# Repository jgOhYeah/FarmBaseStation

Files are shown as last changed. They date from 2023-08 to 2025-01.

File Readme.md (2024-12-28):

# Base station for connecting remote sensors to Thingsboard.
Remote sensors use [PJON over LoRa](https://github.com/gioblu/PJON) radio to communicate.
The [Thingsboard Gateway MQTT API](https://thingsboard.io/docs/reference/gateway-mqtt-api/) is used to connect on the Thingsboard side.

See [here](https://github.com/jgOhYeah/Farm-PJON-LoRa-network) for other sensors and more information on the system.

Written by Jotham Gates
August 2023

## Photos
<!-- <img src="Photos/Inside.jpg" alt="Inside the enclosure." width="50%">
<img src="Photos/Completed.jpg" alt="The completed unit." width="49%"> -->
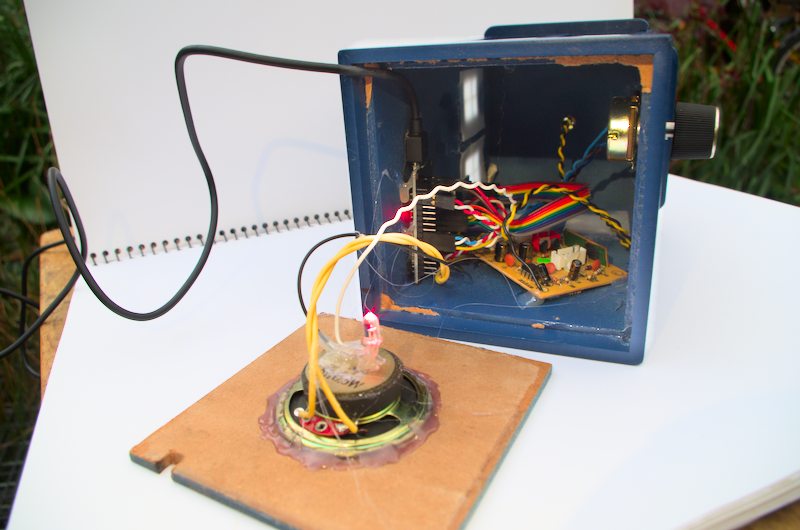
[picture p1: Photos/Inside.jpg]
Inside the enclosure.

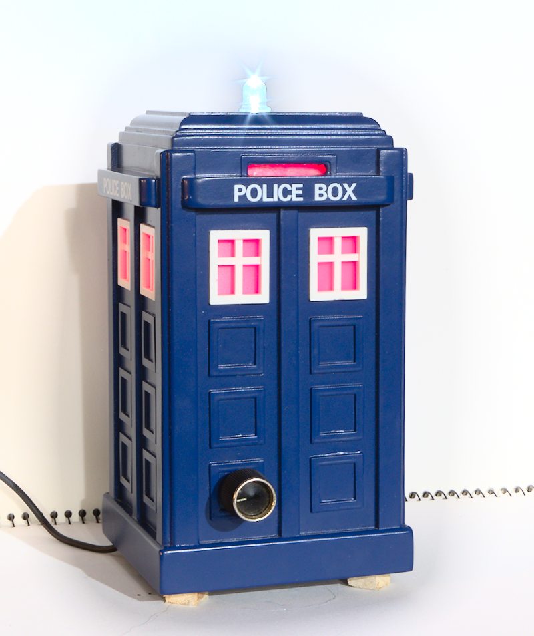
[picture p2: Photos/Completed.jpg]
The completed unit.


## Getting started
The Github repository containing all design files and code is [here](https://github.com/jgOhYeah/FarmBaseStation).

1. Install Platform IO.
2. Open the project in the [`BaseStationCode`](./BaseStationCode/) directory.
3. Create a copy of [`BaseStationCode/credentials.example.ini`](./BaseStationCode/credentials.example.ini) and name this `credentials.ini`. Fill out the settings in this file for the WiFi network to connect to, MQTT broker, Thingsboard credentials and Over The Air (OTA) update settings.
4. Upload the code to the ESP32.
5. Assemble the electronics as shown in the schematics and optionally place inside a case.
6. Test with other sensors and the Thingsboard server.

## Updating using OTA updates
Over the air (OTA) updates can be used to update the software on the base station once it has been programmed for the first time. To do this:
1. Edit the upload port and auth flags in `credentials.ini` to match those currently set on the device.
2. Change the active Platform IO environment to `Tardis-OTA` from its default `Tardis` environment (likewise for the `TVAnt` environemnt for ethernet).
3. Compile and upload code as normal.

## Schematics
The base station uses an ESP32 development board as its base. An SX1278 LoRa radio module breakout board is connected via jumper leads. LEDs are soldered along with their respective current limiting resistors to wires that can be plugged into the ESP32 board. An audio amplifier and speaker can also be connected for alarm functionality. I salvaged this from the sound effects module of a broken children's ride on toy car.

The schematic for the base station

## Fun part / experiments
I originally planned to use the build in DAC of the ESP32 to play sounds on alarm conditions. At this point I haven't succeded in this (currently using the [TunePlayer](https://github.com/jgOhYeah/TunePlayer) library to play simple monotonic songs instead). I did come across the [ESP32-A2DP](https://github.com/pschatzmann/ESP32-A2DP) library that allows the use of this unit as a terrible sounding bluetooth speaker.

[This sketch](Fun/BluetoothSpeaker/BluetoothSpeaker.ino) is the `bt_music_receiver_to_internal_dac` example from the ESP32-A2DP library with the addition of flashing lights.

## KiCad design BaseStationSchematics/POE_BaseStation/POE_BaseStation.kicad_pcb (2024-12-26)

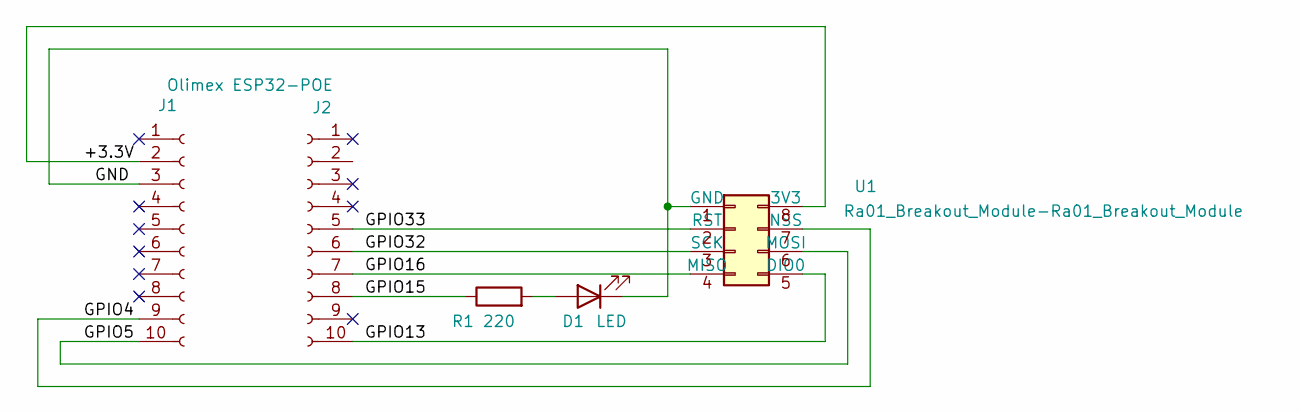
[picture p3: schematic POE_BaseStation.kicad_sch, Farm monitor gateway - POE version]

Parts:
D1: LED; LED_D3.0mm
J1: Olimex ESP32-POE; PinSocket_1x10_P2.54mm_Vertical
J2: Conn_01x10_Socket; PinSocket_1x10_P2.54mm_Vertical
R1: 220; R_Axial_DIN0207_L6.3mm_D2.5mm_P15.24mm_Horizontal
U1: Ra01_Breakout_Module-Ra01_Breakout_Module; DIP-8_W7.62mm_Socket_LongPads

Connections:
/+3.3V: J1.2, U1.8 (3V3)
/GND: D1.1 (K), J1.3, U1.1 (GND)
/GPIO4: J1.9, U1.7 (NSS)
/GPIO5: J1.10, U1.6 (MOSI)
/GPIO13: J2.10, U1.5 (DIO0)
/GPIO15: J2.8, R1.1
/GPIO16: J2.7, U1.4 (MISO)
/GPIO32: J2.6, U1.3 (SCK)
/GPIO33: J2.5, U1.2 (RST)
unnamed: D1.2 (A), R1.2

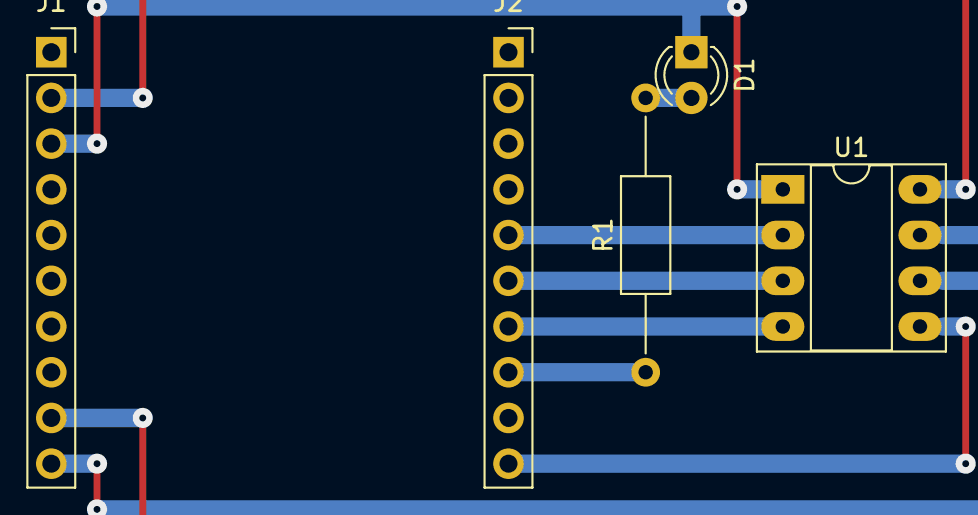
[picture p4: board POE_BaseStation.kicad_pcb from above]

Board: 2 copper layers, 5 parts (0 on the bottom side), 10 nets.

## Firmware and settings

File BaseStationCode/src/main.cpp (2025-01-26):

/**
 * @file ESP32BaseStation.ino
 * @brief Main file for a base station to connect to remote sensors on a farm.
 *
 * This is a base station to convert between PJON through LoRa to Thingsboard
 * MQTT.
 *
 * @author Jotham Gates
 * @version 0.1
 * @date 2024-12-19
 */
#include "defines.h"

#ifdef USE_ETHERNET
NetworkClient client;
PubSubClient mqtt(client);
bool ethernetConnected = false;
#else
WiFiClient wifi;
PubSubClient mqtt(wifi);
#endif
PJONThroughLora bus(PJON_DEVICE_ID);
QueueHandle_t alarmQueue;
#ifdef PIN_SPEAKER
QueueHandle_t audioQueue;
#endif
QueueHandle_t mqttPublishQueue;
SemaphoreHandle_t loraMutex;
SemaphoreHandle_t mqttMutex;
SemaphoreHandle_t serialMutex;

#include "device_list.h"
#include "src/networking.h"
#include "src/lora.h"
#include "src/rpc.h"
#include "src/alarm.h"
#include "src/audio.h"
#include "src/leds.h"
#include "src/ota.h"
#include "src/timeseries.h"

// States used for LED control.
SemaphoreHandle_t stateUpdateMutex;
AlarmState alarmState;
NetworkState networkState;
uint32_t lastLoRaTime;
TaskHandle_t ledTaskHandle;
bool otaUpdating = false;

#ifdef PIN_IR
#include "hvacir.h"
HVAC airConditioner(PIN_IR);
#endif

#define PIO_VERSION_STR "Env=" PIO_ENV ", Platform=" PIO_PLATFORM " (" PIO_PLATFORM_VERSION "), FRAMEWORK=" PIO_FRAMEWORK "."

void setup()
{
#ifdef PIN_SPEAKER
    // In case a reset pccured at the wrong time.
    pinMode(PIN_SPEAKER, OUTPUT);
    digitalWrite(PIN_SPEAKER, LOW);
    audioQueue = xQueueCreate(3, sizeof(AlarmState));
#endif

    // Setup queues and mutexes
    // TODO: Swap to notifications
    alarmQueue = xQueueCreate(3, sizeof(AlarmState));
    mqttPublishQueue = xQueueCreate(15, sizeof(MqttMsg));
    mqttMutex = xSemaphoreCreateMutex();
    serialMutex = xSemaphoreCreateMutex(); // Needs to be created before logging anything.
    loraMutex = xSemaphoreCreateMutex();
    stateUpdateMutex = xSemaphoreCreateMutex();

    Serial.begin(SERIAL_BAUD); // Already running from the bootloader.
    // Serial.setDebugOutput(true);
    LOGI("Setup", "Farm PJON LoRa base station v" VERSION ". Compiled " __DATE__ ", " __TIME__ ". Connecting using " CONNECTION_METHOD ".");
    LOGI("Setup", PIO_VERSION_STR);

    if (!alarmQueue ||
#ifdef PIN_SPEAKER
        !audioQueue ||
#endif
        !mqttPublishQueue || !mqttMutex || !serialMutex || !loraMutex || !stateUpdateMutex)
    {
        LOGE("SETUP", "Could not create something!!!");
    }

    // Setup IR pin if fitted
#ifdef PIN_IR
    airConditioner.begin();
#endif

    // Create tasks
    xTaskCreatePinnedToCore(
        networkingTask,
        "Networking",
        4096,
        NULL,
        1,
        NULL,
        1);

    // xTaskCreatePinnedToCore(
    //     fakeReceiveTask,
    //     "FakeData",
    //     4096,
    //     NULL,
    //     1,
    //     NULL,
    //     1);

    xTaskCreatePinnedToCore(
        pjonTask,
        "PJON",
        4096,
        NULL,
        1,
        NULL,
        1);

    xTaskCreatePinnedToCore(
        alarmTask,
        "Alarm",
        4096,
        NULL,
        1,
        NULL,
        1);

#ifdef PIN_SPEAKER
    xTaskCreatePinnedToCore(
        audioTask,
        "Audio",
        2048,
        NULL,
        1,
        NULL,
        1);
#endif

    xTaskCreatePinnedToCore(
        loraTxTask,
        "LoRa TX",
        4096,
        NULL,
        1,
        NULL,
        1);

    xTaskCreatePinnedToCore(
        ledTask,
        "LEDs",
        2048,
        NULL,
        1,
        &ledTaskHandle,
        1);

#ifdef GENERATE_TIMESERIES
    xTaskCreatePinnedToCore(
        timeseriesTask,
        "TS",
        4096,
        NULL,
        1,
        NULL,
        1);
#endif
    // TODO: Actually measure ram and high water marks rather than guessing.

#ifdef OTA_ENABLE
    // Setup OTA
    OTAManager::setupOTA();
#else
    // Don't need the loop, so can remove the main Arduino task.
    vTaskDelete(NULL);
#endif
}

void loop()
{
#ifdef OTA_ENABLE
    OTAManager::handleOTA();
    vTaskDelay(1000 / portTICK_PERIOD_MS);
#endif
}

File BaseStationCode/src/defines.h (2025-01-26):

/**
 * @file defines.h
 * @brief Definitions and other preprocessor and global stuff.
 *
 * @author Jotham Gates
 * @version 0.1
 * @date 2024-12-19
 */
#pragma once

#include <Arduino.h>

// Networking physical layer
#ifdef USE_ETHERNET
#include <ETH.h>
#include <Network.h>
#define CONNECTION_METHOD "Ethernet"
#else
#include <WiFi.h>
#define CONNECTION_METHOD "WiFi"
#endif

// Networking application layers
#include <PubSubClient.h>
#include <ArduinoJson.h>

// LoRa
#define PJON_INCLUDE_TL
#define TL_RESPONSE_DELAY 30 // Started out at 50ms, 20ms is too short, >=30ms works. // The PICAXE microcontrollers on the other end are pretty slow.
#include <PJONThroughLora.h>

// OTA (enable or disable in credentials.h)
#ifdef OTA_ENABLE
#include <ArduinoOTA.h>
#endif

// For alarm tunes
#ifdef PIN_SPEAKER
#include <TunePlayer.h>
#endif

#if defined(GENERATE_TIMESERIES) && defined(USE_BMP180)
#include <Adafruit_BMP085.h>
#endif

#define VERSION "0.2.7"

#define SERIAL_BAUD 115200 // Same as the bootloader.

#define MQTT_TOPIC_SEPARATOR '/'

#define RECONNECT_DELAY 1000
#define MQTT_RETRY_ITERATIONS 20
#define WIFI_RECONNECT_ATTEMPT_TIME 60000 // If not connected in 1 minute, disconnect and attempt again.

// Logging (with mutexes)
#define SERIAL_TAKE() xSemaphoreTake(serialMutex, portMAX_DELAY)
#define SERIAL_GIVE() xSemaphoreGive(serialMutex)
#define LOGV(tag, format, ...)            \
    SERIAL_TAKE();                        \
    log_v("[" tag "] " format, ##__VA_ARGS__); \
    SERIAL_GIVE()
#define LOGD(tag, format, ...)            \
    SERIAL_TAKE();                        \
    log_d("[" tag "] " format, ##__VA_ARGS__); \
    SERIAL_GIVE()
#define LOGI(tag, format, ...)            \
    SERIAL_TAKE();                        \
    log_i("[" tag "] " format, ##__VA_ARGS__); \
    SERIAL_GIVE()
#define LOGW(tag, format, ...)            \
    SERIAL_TAKE();                        \
    log_w("[" tag "] " format, ##__VA_ARGS__); \
    SERIAL_GIVE()
#define LOGE(tag, format, ...)            \
    SERIAL_TAKE();                        \
    log_e("[" tag "] " format, ##__VA_ARGS__); \
    SERIAL_GIVE()

// https://gcc.gnu.org/onlinedocs/gcc-4.8.5/cpp/Stringification.html
#define xstringify(s) stringify(s)
#define stringify(s) #s

#define MAX_ID_TEXT_LENGTH 11
#define MAX_JSON_TEXT_LENGTH 200
#define MAX_TOPIC_LENGTH 50
#define STRINGS_MATCH(A, B) (strcmp(A, B) == 0)

#ifdef DISABLE_PJON
#define PJON_DEVICE_ID 254
#else
#define PJON_DEVICE_ID 255
#endif

#define LORA_LED_FLASH_TIME 100

// Pins
// LORA pins are specified in platformio.ini
// LEDs (Defined in platformio.ini. If not defined, these LEDs will not be used (LED_BUILTIN will always be used).
// Speaker (Defined in platformio.ini. If not defined, no audio capabilities will be included).

#define LORA_CHECK_INTERVAL 30000
#define LORA_TX_INTERVAL 10000
#define LORA_MAX_PACKET_SIZE 50

#include "src/topics.h"

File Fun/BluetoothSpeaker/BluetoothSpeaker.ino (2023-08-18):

/*
  Streaming data from Bluetooth to internal DAC of ESP32
  
  Copyright (C) 2020 Phil Schatzmann
  This program is free software: you can redistribute it and/or modify
  it under the terms of the GNU General Public License as published by
  the Free Software Foundation, either version 3 of the License, or
  (at your option) any later version.
  This program is distributed in the hope that it will be useful,
  but WITHOUT ANY WARRANTY; without even the implied warranty of
  MERCHANTABILITY or FITNESS FOR A PARTICULAR PURPOSE.  See the
  GNU General Public License for more details.
  You should have received a copy of the GNU General Public License
  along with this program.  If not, see <http://www.gnu.org/licenses/>.
*/

// ==> Example to use built in DAC of ESP32

#include "BluetoothA2DPSink.h"

BluetoothA2DPSink a2dp_sink;

void setup() {
  const i2s_config_t i2s_config = {
      .mode = (i2s_mode_t) (I2S_MODE_MASTER | I2S_MODE_TX | I2S_MODE_DAC_BUILT_IN),
      .sample_rate = 44100, // corrected by info from bluetooth
      .bits_per_sample = (i2s_bits_per_sample_t) 16, /* the DAC module will only take the 8bits from MSB */
      .channel_format =  I2S_CHANNEL_FMT_RIGHT_LEFT,
      .communication_format = (i2s_comm_format_t)I2S_COMM_FORMAT_STAND_MSB,
      .intr_alloc_flags = 0, // default interrupt priority
      .dma_buf_count = 8,
      .dma_buf_len = 64,
      .use_apll = false
  };

  a2dp_sink.set_i2s_config(i2s_config);  
  a2dp_sink.start("InternalDAC");  

    pinMode(32, OUTPUT);
    pinMode(33, OUTPUT);
}


void loop() {
    digitalWrite(32, HIGH);
    digitalWrite(33, LOW);
    delay(1000);
    digitalWrite(33, HIGH);
    digitalWrite(32, LOW);
    delay(1000);
}

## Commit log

2023-08-09 Added topics and started device manager
2023-08-09 Moved devices and fields to separate files
2023-08-10 Added all current fields
2023-08-11 Added decoding of payloads to a device
2023-08-12 Added decoding packets and publishing mqtt Need to fix template linking errors
    [defines.h, device_list.h]
2023-08-12 Added fake data as its own task, fixed field conversions
    [lora.cpp]
2023-08-14 Connected alarms to rpc queue, started schematic
    [BaseStationSchematics.kicad_pcb, BaseStationSchematics.kicad_sch]
2023-08-14 Schematic mostly created, added LoRa watchdog task
    [BaseStationSchematics.kicad_sch]
2023-08-16 Added github pages doxygen action
    [BaseStationSchematics.kicad_sch]
2023-08-16 Adding audio, doesn't work when defined / included
    [defines.h]
2023-08-19 Replaced tune with improved one, updated water baby address
    [device_list.h]
2023-08-25 Added images and improved readme
    [BaseStationSchematics.kicad_sch]
2023-11-03 Tidying up, added reset rpc, leds flash as status lights, audio stops on alarm stop.
    [defines.h, device_list.h, lora.cpp]
2023-11-05 LEDs are driven by their own task
2024-01-14 Added OTA update capability and fixed compile warnings in rpc.cpp and audio.cpp
    [defines.h]
2024-01-27 Added temperature and humidity to pump monitor
2024-06-26 Proposed fix for incorrect temperature signs between 0 and -1 degree
2024-09-24 Plotting ADC max and min in plot strain gauge, basic raw compensation in plotter.
2024-12-18 Fixed SW_VERSION typo, added electric fence monitor field and device
    [defines.h, device_list.h]
2024-12-20 Swapped to platform IO
    [defines.h]
2024-12-24 Adding board config to platform.ini, incorrect POE schematic added
    [BaseStationSchematics.kicad_pcb, BaseStationSchematics.kicad_sch, POE_BaseStation.kicad_pcb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]
2024-12-24 Made speaker and external LEDs optional, pins defined in platformio.ini
    [POE_BaseStation.kicad_sch]
2024-12-26 Schematic and board layout matches POE, started adding ethernet support
    [POE_BaseStation.kicad_pcb, POE_BaseStation.kicad_sch]
2024-12-28 Fixed logging messages not showing
    [defines.h, lora.cpp, main.cpp]
2024-12-30 Added temperature to fence monitor, hopefully fixed attribute on reconnect blocking, flashes LEDs whilst updating.
    [defines.h, device_list.h, main.cpp]
2025-01-04 Added barometer and local timeseries
    [BaseStationSchematics.kicad_pcb, BaseStationSchematics.kicad_sch]
2025-01-26 Started to implement air conditioner IR, printing reset reason and time to attribute.
    [BaseStationSchematics.kicad_sch]
